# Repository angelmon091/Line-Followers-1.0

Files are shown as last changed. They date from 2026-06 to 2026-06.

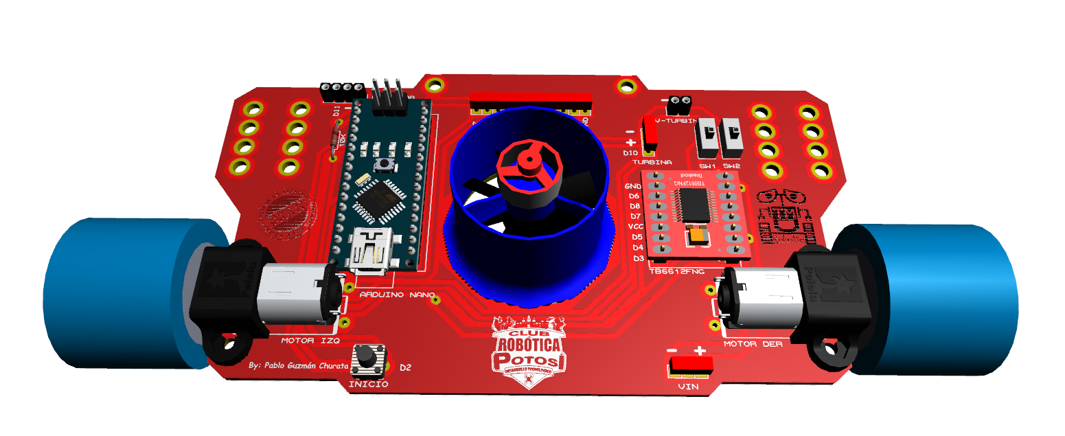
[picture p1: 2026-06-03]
Imagenes Turbinas/11.PNG

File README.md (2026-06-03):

# Line Follower 1.0

   

Robot seguidor de línea — código Arduino, esquemas KiCad y Gerbers listos para fabricación.

Qué es:
- Código, PCB y archivos Gerber para un robot seguidor de línea (ejemplos en `CODE/Main Code/`).

Cómo reproducir (resumen):
1. Materiales: placa Arduino (Uno/Nano/Pro Mini), motores, driver de motores, sensores IR, batería, cables, PCB o protoboard.
2. Abrir el ejemplo: `CODE/Main Code/<ejemplo>/*.ino`.
3. Instalar librerías desde `CODE/Libreria/` y seleccionar la `board` correcta en Arduino IDE/PlatformIO.
4. Compilar y subir al microcontrolador.
5. Montar la electrónica según `ESQUEMA Y PCB/` y/o fabricar la PCB usando `Archivos Gerber PCB/gerbers/` (enviar a fabricante).

Notas importantes:
- Verificar voltaje y polaridad de la batería.
- Calibrar sensores antes de pruebas.
- Revisar conexiones del driver de motores para evitar cortocircuitos.

Estructura del proyecto (estilo `eza --tree`):
```
.
├─ CODE/
│  ├─ Libreria/
│  └─ Main Code/
│     ├─ Codigo Carro V1.0/
│     │  └─ Programacion.ino
│     ├─ Ejemplo de Lectura y Posicion/
│     │  └─ LECTURA_Y_POSICION.ino
│     └─ Ejemplo de Motores y Rotacion/
│        └─ Motores.ino
├─ ESQUEMA Y PCB/
│  ├─ asda.kicad_pcb
│  └─ asda.kicad_sch
├─ Archivos Gerber PCB/
│  └─ gerbers/
│     ├─ asda-F_Cu.gbr
│     └─ asda-job.gbrjob
├─ GErber con Turbina/
└─ README.md
```

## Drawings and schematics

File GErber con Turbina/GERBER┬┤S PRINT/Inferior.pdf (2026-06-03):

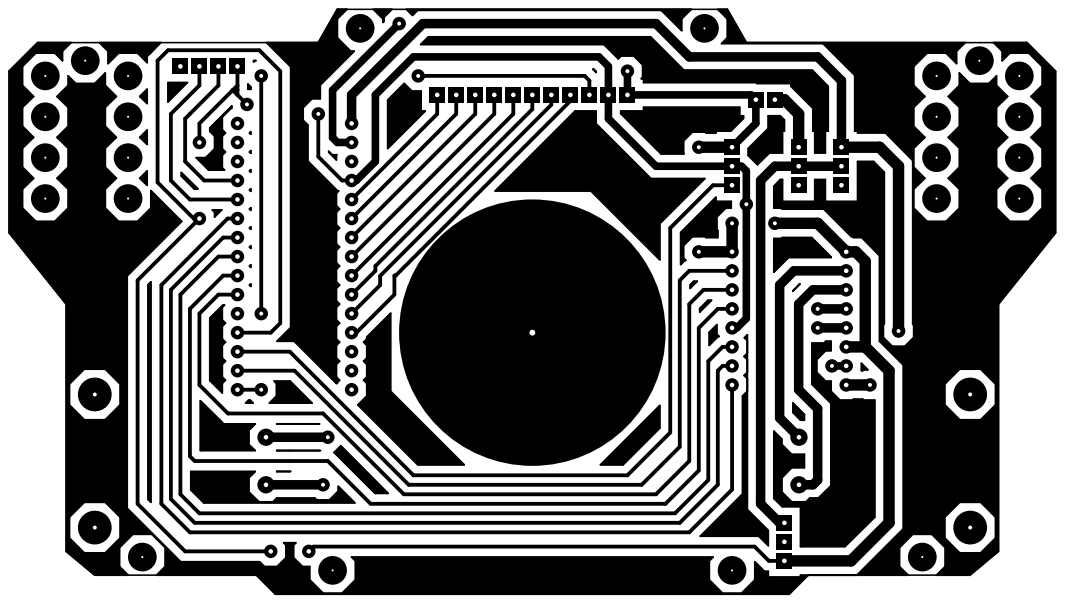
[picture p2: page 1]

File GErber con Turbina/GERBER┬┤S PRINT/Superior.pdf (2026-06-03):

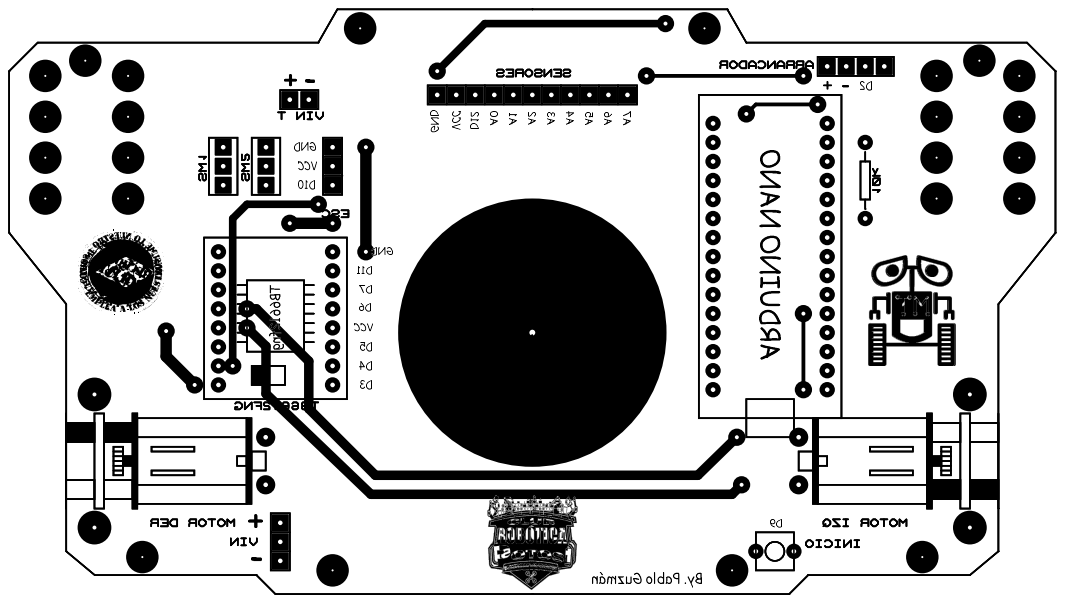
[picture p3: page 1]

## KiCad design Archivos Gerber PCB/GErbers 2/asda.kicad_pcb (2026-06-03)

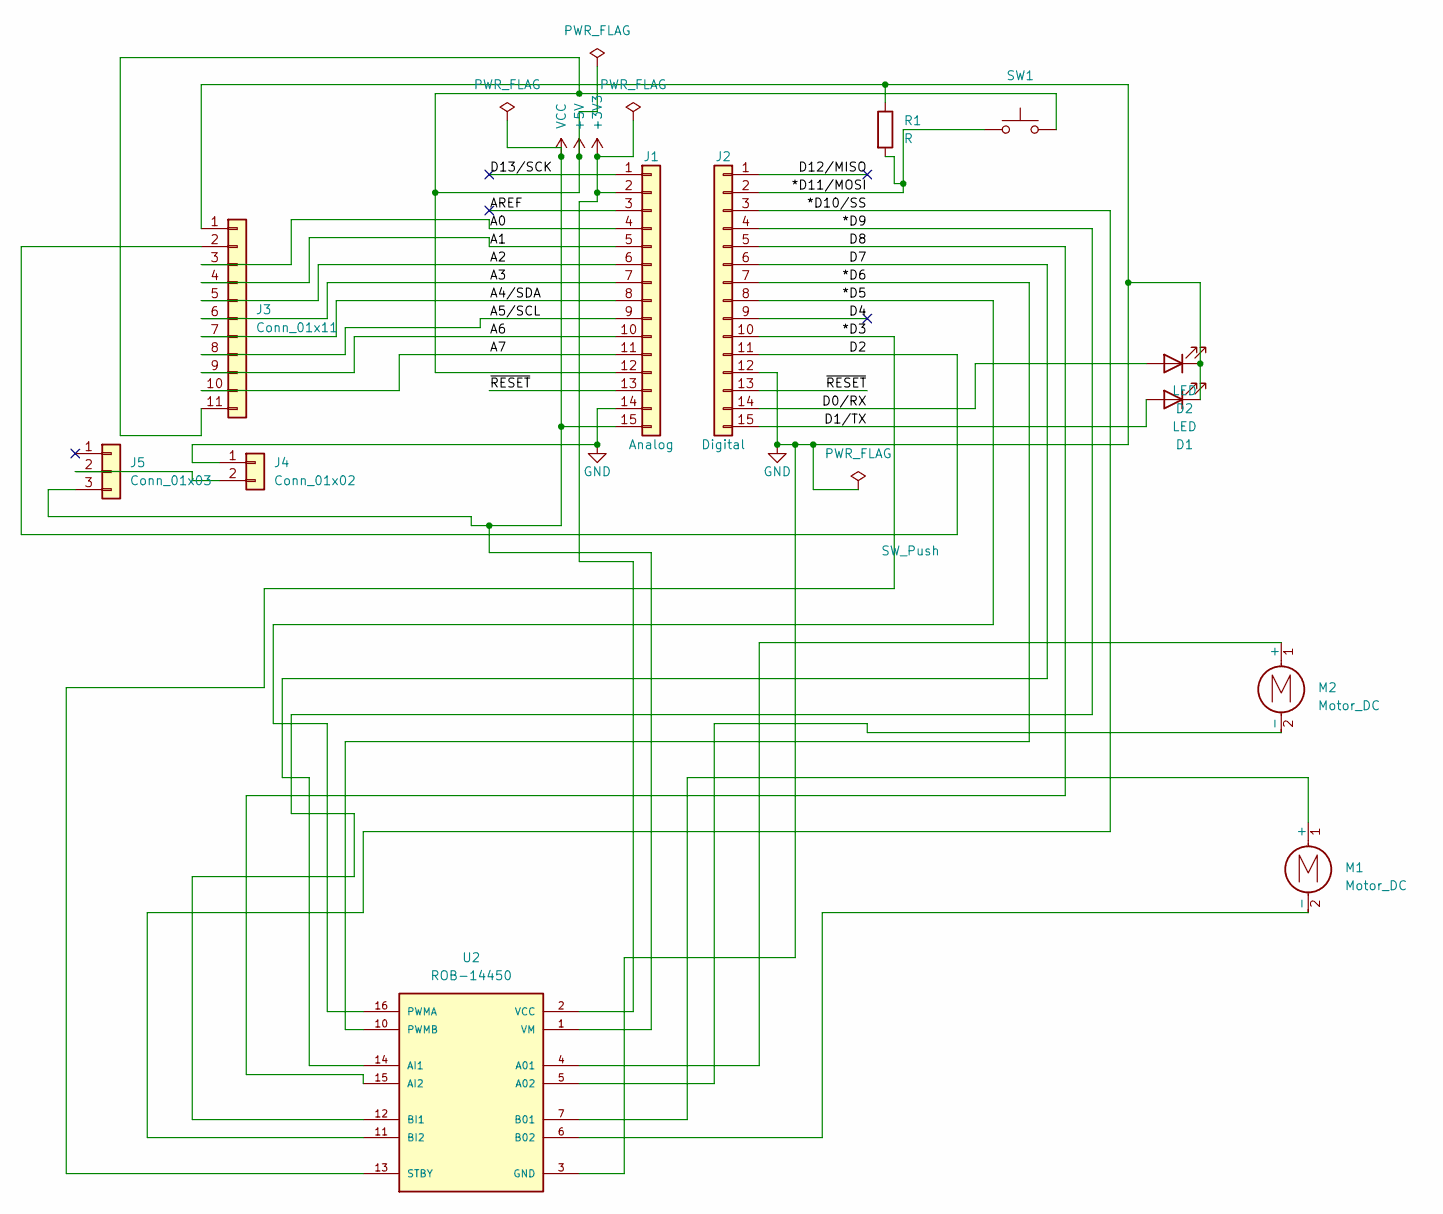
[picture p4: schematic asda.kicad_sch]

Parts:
D1, D2: LED; LED_D5.0mm
J1: Analog; PinHeader_1x15_P2.54mm_Vertical
J2: Digital; PinHeader_1x15_P2.54mm_Vertical
J3: Conn_01x11; PinHeader_1x11_P2.54mm_Vertical
J4: Conn_01x02; PinHeader_1x02_P2.54mm_Vertical
J5: Conn_01x03; PinHeader_1x03_P2.54mm_Vertical
M1, M2: Motor_DC; PinHeader_1x02_P2.54mm_Vertical
R1: R; R_Axial_DIN0207_L6.3mm_D2.5mm_P7.62mm_Horizontal
SW1: SW_Push; SW_PUSH_6mm
U2: ROB-14450; MODULE_ROB-14450; PARTREV 11-13-17

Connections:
+3V3: J1.2, U2.2 (VCC)
+5V: J1.12, J3.11, SW1.2
/*D3: J2.10, U2.13 (STBY)
/*D5: J2.8, U2.16 (PWMA)
/*D6: J2.7, U2.10 (PWMB)
/*D9: J2.4, U2.12 (BI1)
/*D10/SS: J2.3, U2.11 (BI2)
/*D11/MOSI: J2.2, R1.2, SW1.1
/A0: J1.4, J3.3
/A1: J1.5, J3.4
/A2: J1.6, J3.5
/A3: J1.7, J3.6
/A4/SDA: J1.8, J3.7
/A5/SCL: J1.9, J3.8
/A6: J1.10, J3.9
/A7: J1.11, J3.10
/AREF: J1.3
/D0/RX: D2.2 (A), J2.14
/D1/TX: D1.2 (A), J2.15
/D2: J2.11, J3.2
/D4: J2.9
/D7: J2.6, U2.14 (AI1)
/D8: J2.5, U2.15 (AI2)
/D12/MISO: J2.1
/D13/SCK: J1.1
/~RESET: J1.13, J2.13
GND: D1.1 (K), D2.1 (K), J1.14, J2.12, J3.1, J4.1, R1.1, U2.3 (GND), U2.8 (GND), U2.9 (GND)
unnamed: J4.2, J5.2
unnamed: M1.1 (+), U2.7 (B01)
unnamed: M1.2 (-), U2.6 (B02)
unnamed: M2.1 (+), U2.4 (A01)
unnamed: M2.2 (-), U2.5 (A02)
VCC: J1.15, J5.3, U2.1 (VM)

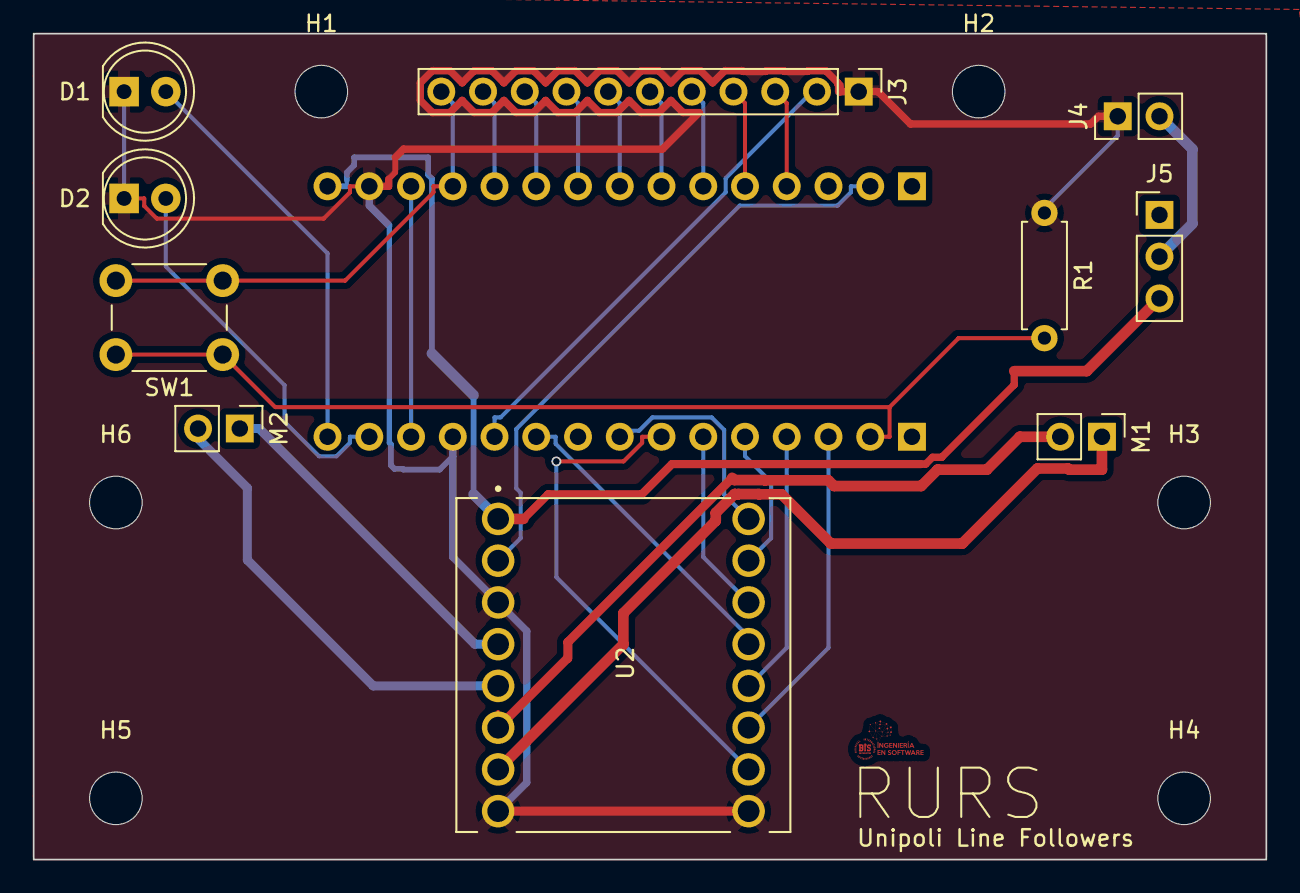
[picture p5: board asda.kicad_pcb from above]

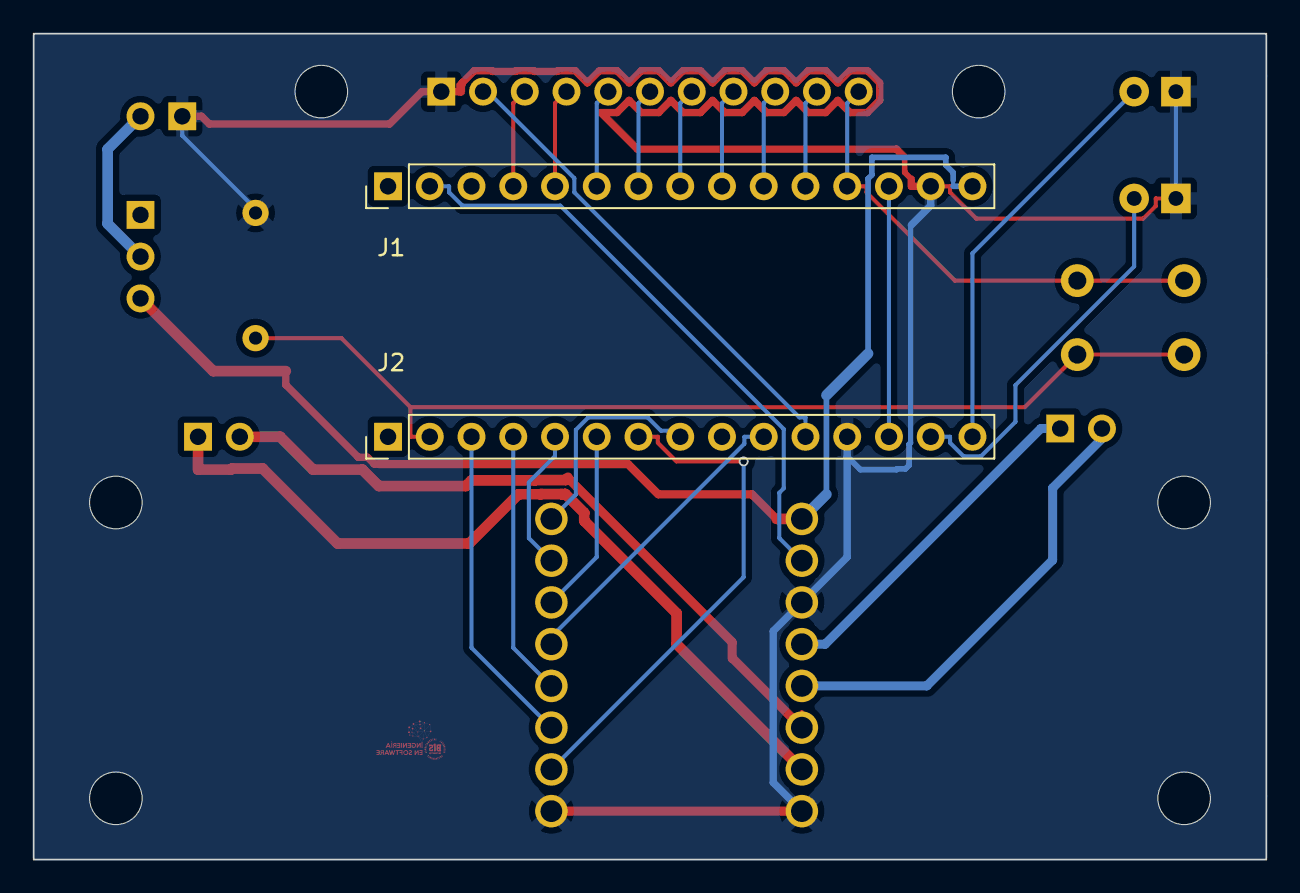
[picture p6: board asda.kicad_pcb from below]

Board: 2 copper layers, 75.0 x 50.2 mm, 18 parts (2 on the bottom side), 29 nets.

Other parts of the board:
H1, H2, H3, H4, H5, H6: MountingHole_3.2mm_M3

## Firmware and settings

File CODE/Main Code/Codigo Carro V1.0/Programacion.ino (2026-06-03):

#define LED_NEGRO 11
#define LED_BLANCO 10
#define AIN1 2
#define AIN2 12
#define PWMA 5
#define BIN1 4
#define BIN2 7
#define PWMB 6
#define STBY 9
int sensorPins[8] = {A0, A1, A2, A3, A4, A5, A6, A7};
int sensorValores[8];
int sensorValores_B[8];
int sensorValores_N[8];
int Muestras[8];
int Valor_Digital[8];
// Posiscion 
int x, y, p, plast;
int pesos[8] = {700, 600, 500, 400, 300, 200, 100, 0};
int setpoint = 350;
// PID
int last_error = 0;
void setup() {
  Serial.begin(115200);
  pinMode(LED_NEGRO, OUTPUT);
  pinMode(LED_BLANCO, OUTPUT);
  pinMode(STBY, OUTPUT);
  digitalWrite(STBY, HIGH);
  motoresInit();
  //calculo de sensor negro
  digitalWrite(LED_NEGRO, HIGH);
  unsigned long t0 = millis();
  while (millis() - t0 < 3000) {
    for (int i = 0; i < 8; i++)
      sensorValores_N[i] = analogRead(sensorPins[i]);
  }
  digitalWrite(LED_NEGRO, LOW);
  delay(400);
  //calculo de sesnores en blanco
  digitalWrite(LED_BLANCO, HIGH);
  t0 = millis();
  while (millis() - t0 < 3000) {
    for (int i = 0; i < 8; i++)
      sensorValores_B[i] = analogRead(sensorPins[i]);
  }
  digitalWrite(LED_BLANCO, LOW);
  for (int i = 0; i < 8; i++)
    Muestras[i] = (sensorValores_B[i] + sensorValores_N[i]) / 2;
  Serial.println("Calibración lista – Siguiendo linea");
}
void loop() {
  leerSensores();
  calcularPosicion();
  int potencia = PID(p, 0.332, 1.095);
  int baseSpeed = 120;
  int left = baseSpeed + potencia;
  int right = baseSpeed - potencia;
  left = constrain(left, -255, 255);
  right = constrain(right, -255, 255);
  Motores(left, right);
  imprimirDatos();
  delay(10);
}
void leerSensores() {
  for (int i = 0; i < 8; i++) {
    int lectura = analogRead(sensorPins[i]);
    sensorValores[i] = lectura;
    // Línea blanca
    Valor_Digital[i] = (lectura < Muestras[i]) ? 1 : 0;
  }
}
void calcularPosicion() {
  x = 0;
  y = 0;
  for (int i = 0; i < 8; i++) {
    x += pesos[i] * Valor_Digital[i];
    y += Valor_Digital[i];
  }
  if (y == 0) p = -1;  // fuera de línea ( estamos tomando si el ultimo registro es mayo r o menor que 350 para saber por cual lado salio el carro)
  else p = x / y;
  if (plast <= 350 && p == -1) p = 0;     // izquierda
  if (plast >= 350 && p == -1) p = 700;   // derecha
  plast = p;
}
//PID( el PID es una ecuacion matematica para corregir errores de calibracion)
int PID(int pos, float Kp, float Kd) {
  int error = pos - setpoint;
  int derivative = error - last_error;
  last_error = error;
  return (error * Kp) + (derivative * Kd);
}
void motoresInit() {
  pinMode(AIN1, OUTPUT);
  pinMode(AIN2, OUTPUT);
  pinMode(PWMA, OUTPUT);
  pinMode(BIN1, OUTPUT);
  pinMode(BIN2, OUTPUT);
  pinMode(PWMB, OUTPUT);
}
void MotorIz(int value) {
  if (value >= 0) { digitalWrite(AIN1, HIGH); digitalWrite(AIN2, LOW); }
  else { digitalWrite(AIN1, LOW); digitalWrite(AIN2, HIGH); value = -value; }
  analogWrite(PWMA, value);
}
void MotorDe(int value) {
  if (value >= 0) { digitalWrite(BIN1, HIGH); digitalWrite(BIN2, LOW); }
  else { digitalWrite(BIN1, LOW); digitalWrite(BIN2, HIGH); value = -value; }
  analogWrite(PWMB, value);
}
void Motores(int left, int right) {
  MotorIz(left);
  MotorDe(right);
}
/////////////////////////////////////////////////////////////////////////////////////////////////////////////Datos serial
void imprimirDatos() {
  for (int i = 0; i < 8; i++) {
    Serial.print(Valor_Digital[i]);
    Serial.print(" ");
  }
  Serial.print(" | p="); Serial.print(p);
  Serial.print(" x="); Serial.print(x);
  Serial.print(" y="); Serial.println(y);
} 

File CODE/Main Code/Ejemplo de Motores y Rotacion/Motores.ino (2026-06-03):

#define pwmi  3   //PWM LEFT MOTOR
#define izq1  5   //LEFT1 MOTOR
#define izq2  4   //LEFT2 MOTOR
#define pwmd  11  //PWM RIGHT MOTOR
#define der1  6   //RIGHT1 MOTOR
#define der2  7   //RIGHT2 MOTOR
void setup() {
//TCCR2B = TCCR2B & B11111000 | B00000001;
//set timer 2 divisor to     1 for PWM frequency of 31372.55 Hz

//TCCR2B = TCCR2B & B11111000 | B00000010; 
//set timer 2 divisor to     8 for PWM frequency of  3921.16 Hz

TCCR2B = TCCR2B & B11111000 | B00000011;   
//set timer 2 divisor to    32 for PWM frequency of   980.39 Hz

//TCCR2B = TCCR2B & B11111000 | B00000100;   
//set timer 2 divisor to    64 for PWM frequency of   490.20 Hz (The DEFAULT)

//TCCR2B = TCCR2B & B11111000 | B00000101;   
//set timer 2 divisor to   128 for PWM frequency of   245.10 Hz

//TCCR2B = TCCR2B & B11111000 | B00000110;   
//set timer 2 divisor to   256 for PWM frequency of   122.55 Hz

//TCCR2B = TCCR2B & B11111000 | B00000111;   
//set timer 2 divisor to  1024 for PWM frequency of    30.64 Hz

pinMode(izq1,OUTPUT);
pinMode(izq2,OUTPUT);
pinMode(der1,OUTPUT);
pinMode(der2,OUTPUT);
}

void loop() {
motores(20,0); // motores(izq,der)
}


void motores(int izq, int der){//0 hasta 255    0 hasta -255
  ////////////////motor LEFT "IZQUIERDO" ////////////////////////
  if(izq>=0){
    digitalWrite(izq1,HIGH);
    digitalWrite(izq2,LOW);
  }
  else{
    digitalWrite(izq1,LOW);
    digitalWrite(izq2,HIGH);
    izq=izq*(-1);
  }
  analogWrite(pwmi,izq);
  
  ////////////////motor RIGHT "DERECHO" ////////////////////////
  if(der>=0){
    digitalWrite(der1,HIGH);
    digitalWrite(der2,LOW);
  }
  else{
    digitalWrite(der1,LOW);
    digitalWrite(der2,HIGH);
    der=der*(-1);
  }
  analogWrite(pwmd,der);
  
}
